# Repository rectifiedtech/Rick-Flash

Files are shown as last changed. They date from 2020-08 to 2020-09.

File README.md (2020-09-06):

# Rick Flash v1.0

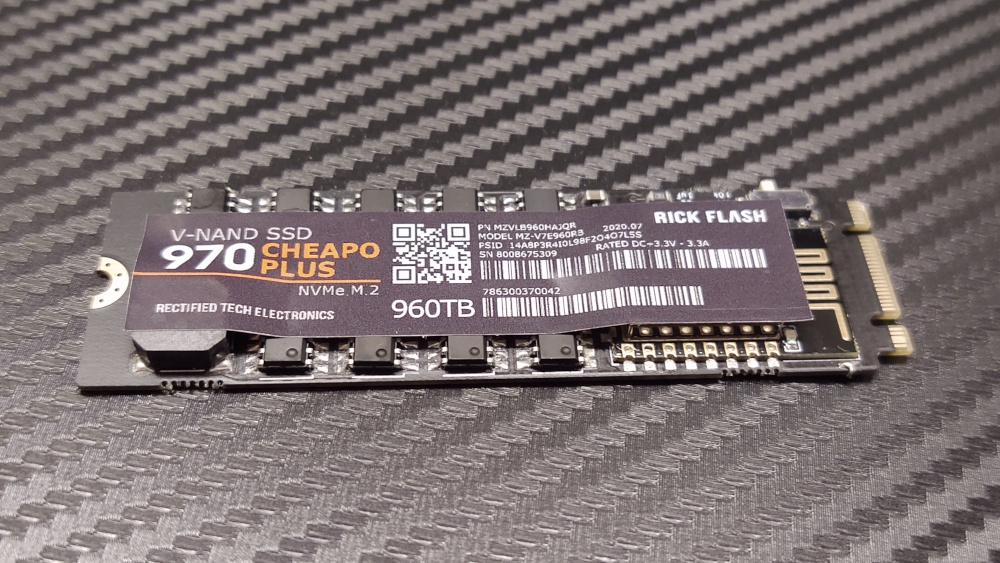
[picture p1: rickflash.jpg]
rickflash

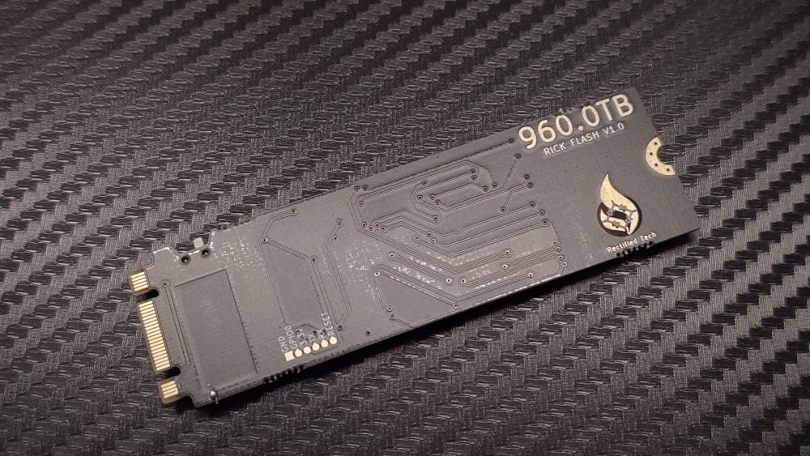
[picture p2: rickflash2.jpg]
rickflash2


### Watch it in action

https://youtu.be/qJRm4iVWZss

(https://www.youtube.com/watch?v=qJRm4iVWZss)

Here's a link to the limited production run of the Rick Flash project - https://www.ebay.com/itm/264855847576 - We might not make anymore of these unless there's more demand.

## Getting Started
1. Insert Rick Flash into an M.2 SSD slot, works with both SATA and NVME SSD slots (B+M Key), keep in mind that the module is a little wider and thicker than a standard M.2 SSD and may not fit in all laptops and desktops perfectly.
2. If the Rick Flash does not make any sound then slide the switch on the side of the M.2 module and try again, you should hear the tune start to play.

## WiFi Connection
### (MAY NOT WORK WITH SOME SAMSUNG PHONES)
When the Rick Flash is powered on it will play a short tune to the Rick Roll song known as “Never Gonna Give You Up” by Rick Astley (you probably already figured this out by now). The Rick Flash creates a WiFi access point called “Free WiFi!”, when connected to it via a phone or computer you will be redirected to a captive portal web page (you may have to tap on “Sign in to Free WiFi!”) on the device that displays “You Got Rick Rolled!!!” with a GIF of Rick Astley along with the lyrics to the song. You can also trigger the song to replay using the web page interface (See Below).

## Remote control over WiFi
1. Power on the Rick Flash and wait until the song stops playing.
2. Connect to the WiFi network called “Free WiFi!” and you should be redirected to a page with a GIF of Rick Astley.
3. Click on the hyperlink called “Click here to trigger the Rick Flash!” and it will replay the song on the Rick Flash remotely. Keep in mind that the WiFi connection may drop out during the song playback and you can only trigger it to replay after the song finishes.

## Programming Pads
The Rick Flash can be reprogrammed using the Arduino IDE and connecting the appropriate pins from a WEMOS D1 Mini Board (without the ESP module soldered) to the programming pads on the back of the M.2 module.

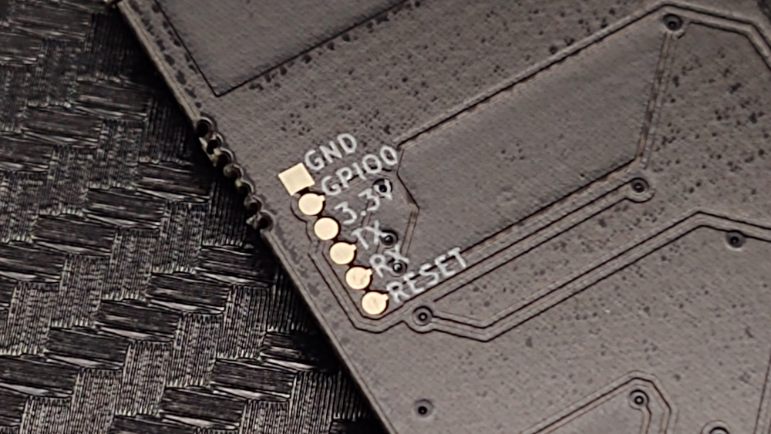
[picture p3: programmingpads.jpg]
programming pads


### Programming the ESP8266
Connect a headless WEMOS D1 Mini board to the Programming pads then upload your code using the arduino IDE with the WEMOS D1 Mini Board selected. Also make sure to write the html and image files to the ESP8266 via SPIFFS by selecting Tools --> ESP8266 Sketch Data Upload. You may need to add the ESP8266 boards to your boards manager as well as the libraries used in the original Arduino code.

## Bill of Materials
| | | | | 
|-----|---|---|---|
| Qty | Description | LCSC #  | Link | 
| 1 | PCB | - | Manufacturer of choice | 
| 1 | ESP-12E | C89297  | https://lcsc.com/product-detail/WIFI-Modules_ESP-12E_C89297.html | 
| 1 | Piezo Buzzer MLT-8530 | C94599  | https://lcsc.com/product-detail/Buzzers_Jiangsu-Huaneng-Elec-MLT-8530_C94599.html | 
| 1 | SMD Slide Swith MSK12C02 | C431540 | https://lcsc.com/product-detail/Toggle-Switches_SHOU-HAN-MSK12C02_C431540.html | 
| 9 | Padauk Microcontroller PMS152-S16 | C317590 | https://lcsc.com/product-detail/PADAUK_PADAUK-Tech-PMS152-S16_C317590.html | 
| 4 | 10k 0805 Resistor | C343942 | https://lcsc.com/product-detail/Chip-Resistor-Surface-Mount_FH-Guangdong-Fenghua-Advanced-Tech-RC-05K103JT_C343942.html | 
| 1 | 1uF 0805 Capacitor | C344171 | https://lcsc.com/product-detail/Others_CCTC-TCC0805X7R105K250DTS_C344171.html |

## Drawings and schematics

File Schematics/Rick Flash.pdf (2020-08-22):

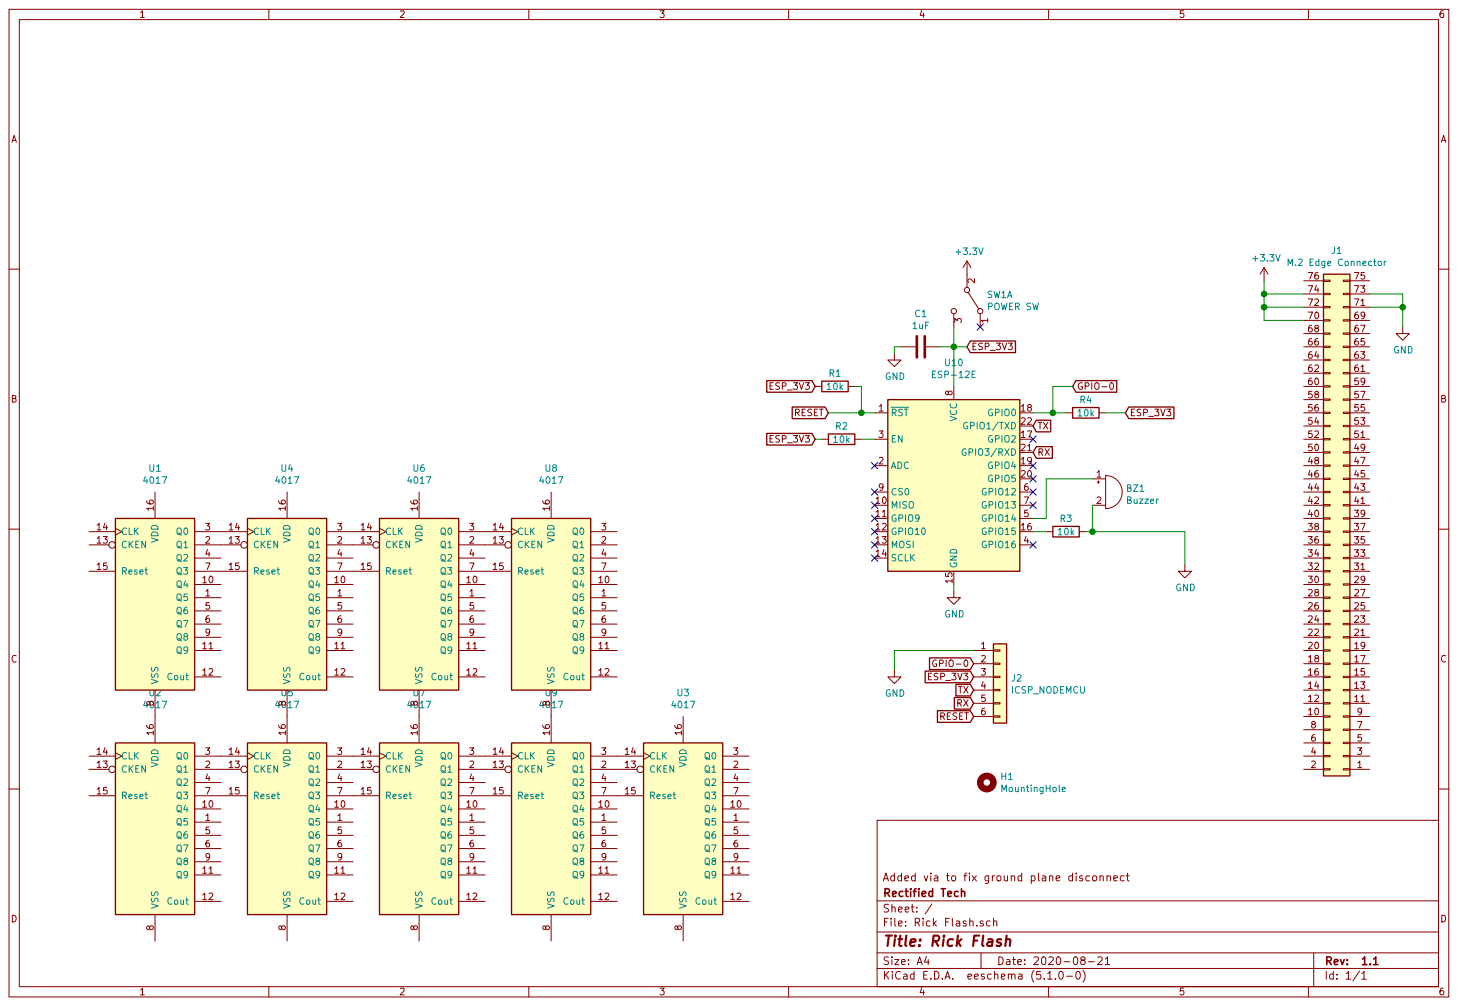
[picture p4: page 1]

Id: 1/1 Title: Rick Flash

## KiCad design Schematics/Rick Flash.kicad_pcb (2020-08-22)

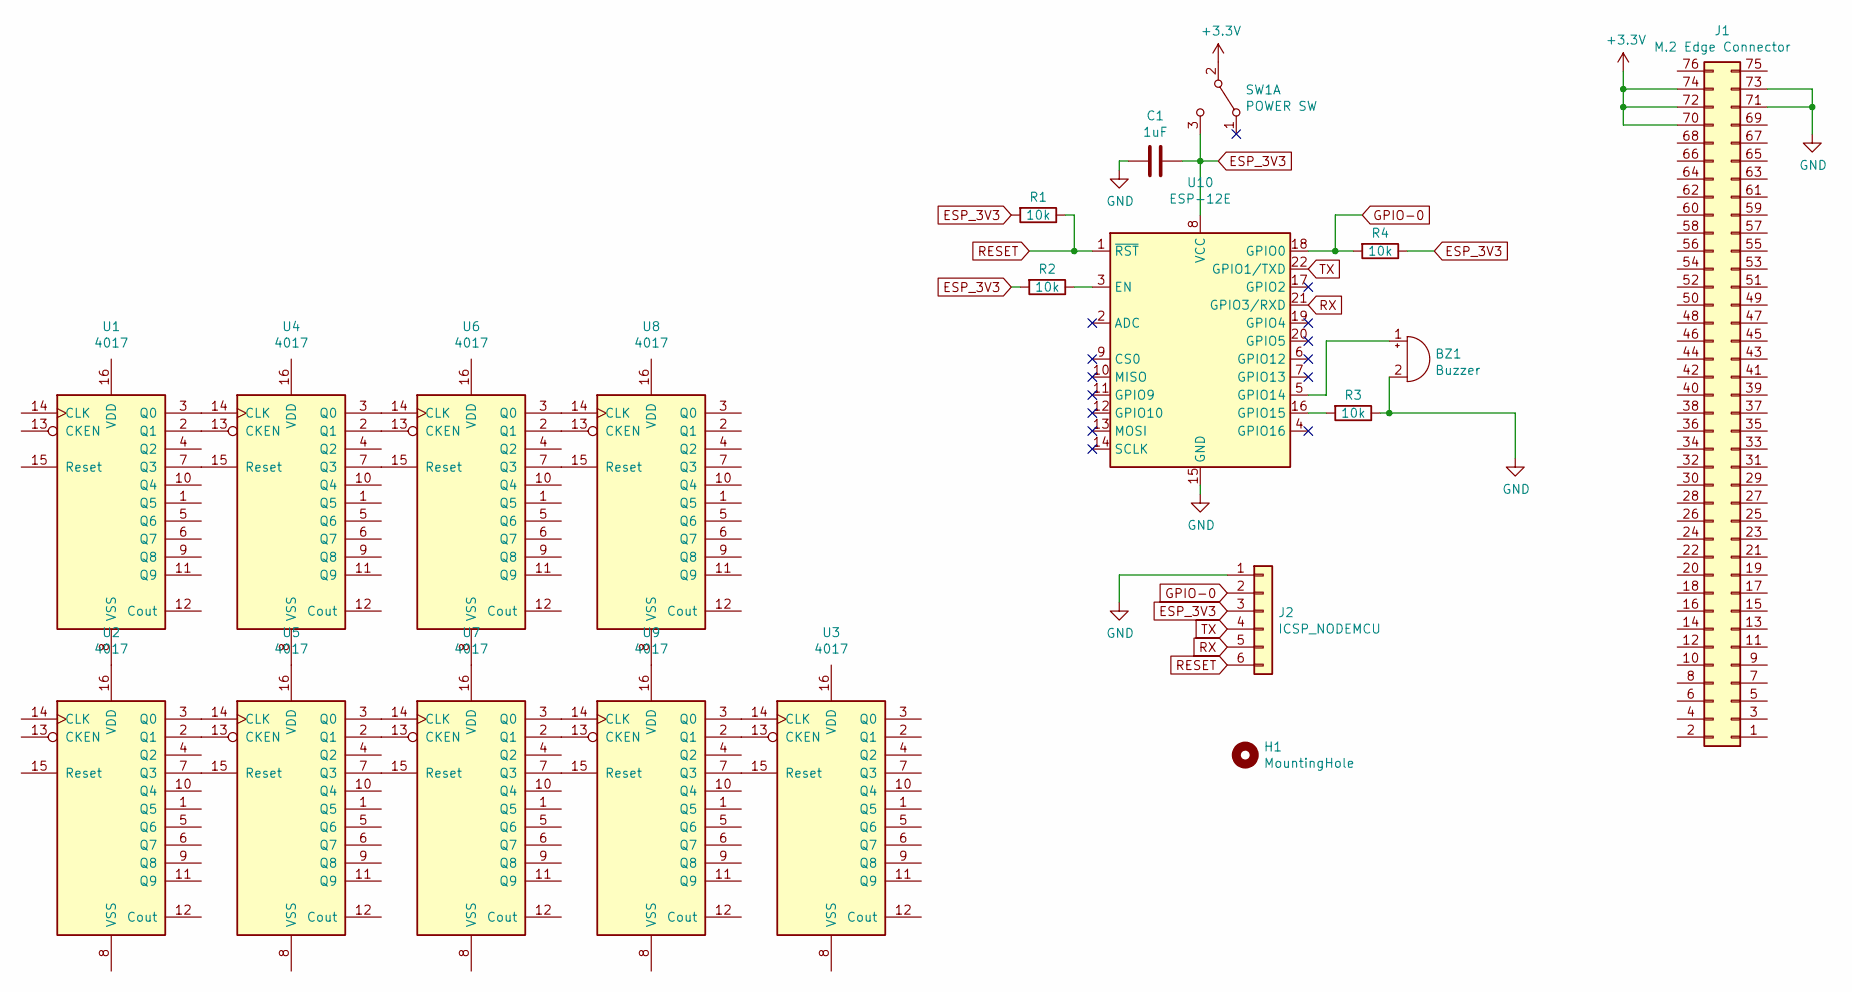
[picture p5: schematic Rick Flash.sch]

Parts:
BZ1: Buzzer; PUIAudio_SMT_0825_S_4_R
C1: 1uF; C_0805_2012Metric
H1: MountingHole; MountingHole_3.2mm_M3_Pad_Via
J1: M.2 Edge Connector; NGFF_B+M
J2: ICSP_NODEMCU; 6pin 1.27mm ICSP Pad
R1, R2, R3, R4: 10k; R_0805_2012Metric
SW1: POWER SW; SW_SPDT_PCM12
U1, U2, U3, U4, U5, U6, U7, U8, U9: 4017; SOP-16_4.4x10.4mm_P1.27mm
U10: ESP-12E

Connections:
+3V3: J1.70, J1.72, J1.74, SW1.2 (B)
ESP_3V3: C1.1, J2.3, R1.2, R2.2, R4.1, SW1.3 (C), U10.8 (VCC)
GND: BZ1.2 (+), C1.2, J1.71, J1.73, J2.1, R3.1, U10.15 (GND)
GPIO-0: J2.2, R4.2, U10.18 (GPIO0)
unnamed: BZ1.1 (-), U10.5 (GPIO14)
unnamed: R2.1, U10.3 (EN)
unnamed: R3.2, U10.16 (GPIO15)
unnamed: U1.2 (Q1), U4.13 (CKEN)
unnamed: U1.3 (Q0), U4.14 (CLK)
unnamed: U1.7 (Q3), U4.15 (Reset)
unnamed: U1.8 (VSS), U2.16 (VDD)
unnamed: U2.2 (Q1), U5.13 (CKEN)
unnamed: U2.3 (Q0), U5.14 (CLK)
unnamed: U2.7 (Q3), U5.15 (Reset)
unnamed: U3.13 (CKEN), U9.2 (Q1)
unnamed: U3.14 (CLK), U9.3 (Q0)
unnamed: U3.15 (Reset), U9.7 (Q3)
unnamed: U4.2 (Q1), U6.13 (CKEN)
unnamed: U4.3 (Q0), U6.14 (CLK)
unnamed: U4.7 (Q3), U6.15 (Reset)
unnamed: U4.8 (VSS), U5.16 (VDD)
unnamed: U5.2 (Q1), U7.13 (CKEN)
unnamed: U5.3 (Q0), U7.14 (CLK)
unnamed: U5.7 (Q3), U7.15 (Reset)
unnamed: U6.2 (Q1), U8.13 (CKEN)
unnamed: U6.3 (Q0), U8.14 (CLK)
unnamed: U6.7 (Q3), U8.15 (Reset)
unnamed: U6.8 (VSS), U7.16 (VDD)
unnamed: U7.2 (Q1), U9.13 (CKEN)
unnamed: U7.3 (Q0), U9.14 (CLK)
unnamed: U7.7 (Q3), U9.15 (Reset)
unnamed: U8.8 (VSS), U9.16 (VDD)
RESET: J2.6, R1.1, U10.1 (~RST)
RX: J2.5, U10.21 (GPIO3/RXD)
TX: J2.4, U10.22 (GPIO1/TXD)

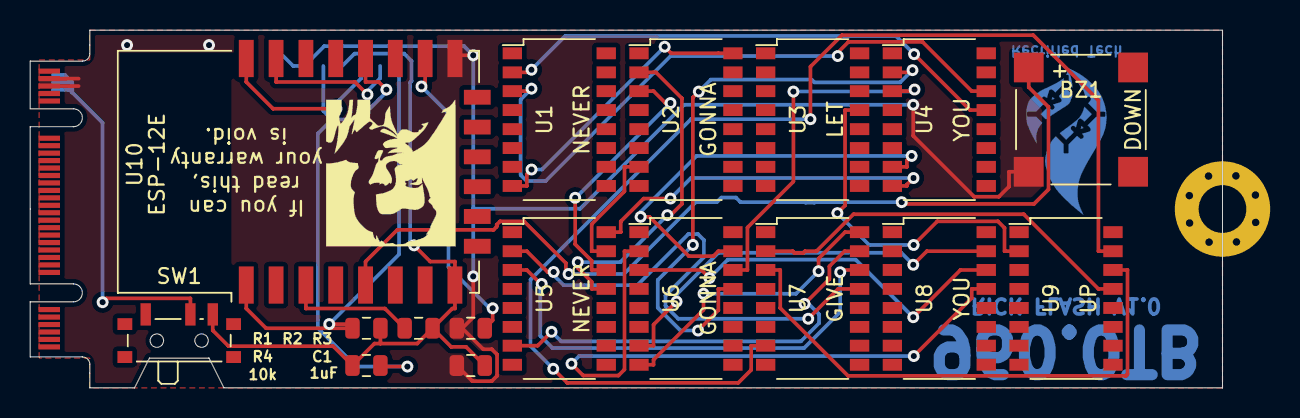
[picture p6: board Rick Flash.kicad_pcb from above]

Board: 2 copper layers, 80.0 x 24.0 mm, 20 parts (1 on the bottom side), 35 nets.

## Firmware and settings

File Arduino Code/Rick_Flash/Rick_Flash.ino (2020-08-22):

//Rick Flash - Designed by Rectified Tech

//Song transposed by robsoncouto


#include <ESP8266WiFi.h>
#include <DNSServer.h>
#include <ESP8266WebServer.h>
#include <ESP8266mDNS.h>
#include <FS.h>

#define NOTE_B0  31
#define NOTE_C1  33
#define NOTE_CS1 35
#define NOTE_D1  37
#define NOTE_DS1 39
#define NOTE_E1  41
#define NOTE_F1  44
#define NOTE_FS1 46
#define NOTE_G1  49
#define NOTE_GS1 52
#define NOTE_A1  55
#define NOTE_AS1 58
#define NOTE_B1  62
#define NOTE_C2  65
#define NOTE_CS2 69
#define NOTE_D2  73
#define NOTE_DS2 78
#define NOTE_E2  82
#define NOTE_F2  87
#define NOTE_FS2 93
#define NOTE_G2  98
#define NOTE_GS2 104
#define NOTE_A2  110
#define NOTE_AS2 117
#define NOTE_B2  123
#define NOTE_C3  131
#define NOTE_CS3 139
#define NOTE_D3  147
#define NOTE_DS3 156
#define NOTE_E3  165
#define NOTE_F3  175
#define NOTE_FS3 185
#define NOTE_G3  196
#define NOTE_GS3 208
#define NOTE_A3  220
#define NOTE_AS3 233
#define NOTE_B3  247
#define NOTE_C4  262
#define NOTE_CS4 277
#define NOTE_D4  294
#define NOTE_DS4 311
#define NOTE_E4  330
#define NOTE_F4  349
#define NOTE_FS4 370
#define NOTE_G4  392
#define NOTE_GS4 415
#define NOTE_A4  440
#define NOTE_AS4 466
#define NOTE_B4  494
#define NOTE_C5  523
#define NOTE_CS5 554
#define NOTE_D5  587
#define NOTE_DS5 622
#define NOTE_E5  659
#define NOTE_F5  698
#define NOTE_FS5 740
#define NOTE_G5  784
#define NOTE_GS5 831
#define NOTE_A5  880
#define NOTE_AS5 932
#define NOTE_B5  988
#define NOTE_C6  1047
#define NOTE_CS6 1109
#define NOTE_D6  1175
#define NOTE_DS6 1245
#define NOTE_E6  1319
#define NOTE_F6  1397
#define NOTE_FS6 1480
#define NOTE_G6  1568
#define NOTE_GS6 1661
#define NOTE_A6  1760
#define NOTE_AS6 1865
#define NOTE_B6  1976
#define NOTE_C7  2093
#define NOTE_CS7 2217
#define NOTE_D7  2349
#define NOTE_DS7 2489
#define NOTE_E7  2637
#define NOTE_F7  2794
#define NOTE_FS7 2960
#define NOTE_G7  3136
#define NOTE_GS7 3322
#define NOTE_A7  3520
#define NOTE_AS7 3729
#define NOTE_B7  3951
#define NOTE_C8  4186
#define NOTE_CS8 4435
#define NOTE_D8  4699
#define NOTE_DS8 4978
#define REST      0


#define DBG_OUTPUT_PORT Serial

const byte DNS_PORT = 53;
const char *ssid = "Free WiFi!";
int clientcount = 0;
int clientcountold = 0;
int minutetimer = 0;

// change this to make the song slower or faster
int tempo = 115;

// change this to whichever pin you want to use
int buzzer = D5;

// notes of the moledy followed by the duration.
// a 4 means a quarter note, 8 an eighteenth , 16 sixteenth, so on
// !!negative numbers are used to represent dotted notes,
// so -4 means a dotted quarter note, that is, a quarter plus an eighteenth!!
int melody[] = {

  // Never Gonna Give You Up - Rick Astley
  // Score available at https://musescore.com/chlorondria_5/never-gonna-give-you-up_alto-sax
  // Arranged by Chlorondria   

  REST,-4, NOTE_A4,8, NOTE_B4,8, NOTE_CS5,8, NOTE_D5,8, NOTE_B4,8, //35
  REST,8, NOTE_E5,8, NOTE_FS5,8, NOTE_E5,-4, NOTE_A4,16, NOTE_B4,16, NOTE_D5,16, NOTE_B4,16,
  NOTE_FS5,-8, NOTE_FS5,-8, NOTE_E5,-4, NOTE_A4,16, NOTE_B4,16, NOTE_D5,16, NOTE_B4,16,
  NOTE_E5,-8, NOTE_E5,-8, NOTE_D5,-8, NOTE_CS5,16, NOTE_B4,8, NOTE_A4,16, NOTE_B4,16, NOTE_D5,16, NOTE_B4,16,
  NOTE_D5,4, NOTE_E5,8, NOTE_CS5,-8, NOTE_B4,16, NOTE_A4,4, NOTE_A4,8, 

  NOTE_E5,4, NOTE_D5,2, NOTE_A4,16, NOTE_B4,16, NOTE_D5,16, NOTE_B4,16, //40
  NOTE_FS5,-8, NOTE_FS5,-8, NOTE_E5,-4, NOTE_A4,16, NOTE_B4,16, NOTE_D5,16, NOTE_B4,16,
  NOTE_A5,4, NOTE_CS5,8, NOTE_D5,-8, NOTE_CS5,16, NOTE_B4,8, NOTE_A4,16, NOTE_B4,16, NOTE_D5,16, NOTE_B4,16,
  NOTE_D5,4, NOTE_E5,8, NOTE_CS5,-8, NOTE_B4,16, NOTE_A4,4, NOTE_A4,8,  
  NOTE_E5,4, NOTE_D5,2, NOTE_A4,16, NOTE_B4,16, NOTE_D5,16, NOTE_B4,16,
   
  NOTE_FS5,-8, NOTE_FS5,-8, NOTE_E5,-4, NOTE_A4,16, NOTE_B4,16, NOTE_D5,16, NOTE_B4,16, //45
  NOTE_A5,4, NOTE_CS5,8, NOTE_D5,-8, NOTE_CS5,16, NOTE_B4,8, NOTE_A4,16, NOTE_B4,16, NOTE_D5,16, NOTE_B4,16,
  NOTE_D5,4, NOTE_E5,8, NOTE_CS5,-8, NOTE_B4,16, NOTE_A4,4, NOTE_A4,8,  
  NOTE_E5,4, NOTE_D5,2, NOTE_A4,16, NOTE_B4,16, NOTE_D5,16, NOTE_B4,16,
  NOTE_FS5,-8, NOTE_FS5,-8, NOTE_E5,-4, NOTE_A4,16, NOTE_B4,16, NOTE_D5,16, NOTE_B4,16, //45
  
  NOTE_A5,4, NOTE_CS5,8, NOTE_D5,-8, NOTE_CS5,16, NOTE_B4,8, NOTE_A4,16, NOTE_B4,16, NOTE_D5,16, NOTE_B4,16,
  NOTE_D5,4, NOTE_E5,8, NOTE_CS5,-8, NOTE_B4,16, NOTE_A4,4, NOTE_A4,8, 

  NOTE_E5,4, NOTE_D5,2, REST,4
};

// sizeof gives the number of bytes, each int value is composed of two bytes (16 bits)
// there are two values per note (pitch and duration), so for each note there are four bytes
int notes = sizeof(melody) / sizeof(melody[0]) / 2;

// this calculates the duration of a whole note in ms
int wholenote = (60000 * 4) / tempo;

int divider = 0, noteDuration = 0;


WiFiEventHandler stationConnectedHandler;
WiFiEventHandler probeRequestPrintHandler;


IPAddress apIP(192, 168, 1, 1);

DNSServer dnsServer;

ESP8266WebServer webServer(80);

void setup() {
 
  Serial.begin(115200);
  Serial.println();

  Serial.print("Configuring access point...");
  
  WiFi.mode(WIFI_AP);
  WiFi.softAPConfig(apIP, apIP, IPAddress(255, 255, 255, 0));
  WiFi.softAP(ssid);

  // if DNSServer is started with "*" for domain name, it will reply with
  // provided IP to all DNS request
  dnsServer.start(DNS_PORT, "*", apIP);

  //start debug port
  DBG_OUTPUT_PORT.begin(115200);
  DBG_OUTPUT_PORT.print("\n");
  DBG_OUTPUT_PORT.setDebugOutput(true);
  SPIFFS.begin();

  //redirect all traffic to index.html
  webServer.onNotFound([]() {
    if(!handleFileRead(webServer.uri())){
      const char *metaRefreshStr = "<head><meta http-equiv=\"refresh\" content=\"0; url=http://192.168.1.1/index.html\" /></head><body><p>redirecting...</p></body>";
      webServer.send(200, "text/html", metaRefreshStr);
    }
  });
  
  webServer.begin();
  
  Serial.print("AP IP address: ");
  Serial.println(apIP);
  Serial.println("HTTP server started");

  stationConnectedHandler = WiFi.onSoftAPModeStationConnected(&onStationConnected);
  probeRequestPrintHandler = WiFi.onSoftAPModeProbeRequestReceived(&onProbeRequestPrint);
Serial.println("Done configuring AP!");
  webServer.on("/trigger", handleTRIGGER); //as Per  <a href="ledOn">, Subroutine to be called

//Play the song (function)
  rickroll(); 

}

//This is used to check to see when a client connects, however it's not used in this code at the moment
void onStationConnected(const WiFiEventSoftAPModeStationConnected& evt) {
  Serial.println("New Client Connected");
  clientcount = (clientcount + 1);
  Serial.println("Total Clients: ");
  Serial.println(clientcount);

}

//HTML action when triggered link is clicked
void handleTRIGGER() { 
 Serial.println("Rick Flash Successfully Triggered");
  rickroll(); //Play the song
//Display that the Rick Flash has been triggered when clicked
 webServer.send(200, "text/html", "Rick Flash Successfully Triggered!"); //Send ADC value only to client ajax request
}

//Can't remember why this is here... It might have something to do with detecting client connections
void onProbeRequestPrint(const WiFiEventSoftAPModeProbeRequestReceived& evt) {
}

//This function plays the song
void rickroll() {
Serial.print("Rick Roll Started...");

for (int thisNote = 0; thisNote < notes * 2; thisNote = thisNote + 2) {

    // calculates the duration of each note
    divider = melody[thisNote + 1];
    if (divider > 0) {
      // regular note, just proceed
      noteDuration = (wholenote) / divider;
    } else if (divider < 0) {
      // dotted notes are represented with negative durations!!
      noteDuration = (wholenote) / abs(divider);
      noteDuration *= 1.5; // increases the duration in half for dotted notes
    }

    // we only play the note for 90% of the duration, leaving 10% as a pause
    tone(buzzer, melody[thisNote], noteDuration * 0.9);

    // Wait for the specief duration before playing the next note.
    delay(noteDuration);

    // stop the waveform generation before the next note.
    noTone(buzzer);
  }
  Serial.print("Rick Roll Ended...");

}

void loop() {



//check to see if a client has connected
  dnsServer.processNextRequest();
  webServer.handleClient();


  //This checks to see if a client connects every 5 seconds
  if (millis() > 5000 && probeRequestPrintHandler) {
    probeRequestPrintHandler = WiFiEventHandler(); 
}

//check to see if a client has connected
if (clientcount > clientcountold){
  
 //put code here to run when a new client connects
}

else {

}
clientcountold = clientcount; //previous client count until value goes up

}


//Web server stuff
String getContentType(String filename){
  if(webServer.hasArg("download")) return "application/octet-stream";
  else if(filename.endsWith(".htm")) return "text/html";
  else if(filename.endsWith(".html")) return "text/html";
  else if(filename.endsWith(".css")) return "text/css";
  else if(filename.endsWith(".js")) return "application/javascript";
  else if(filename.endsWith(".png")) return "image/png";
  else if(filename.endsWith(".gif")) return "image/gif";
  else if(filename.endsWith(".jpg")) return "image/jpeg";
  else if(filename.endsWith(".ico")) return "image/x-icon";
  else if(filename.endsWith(".xml")) return "text/xml";
  else if(filename.endsWith(".pdf")) return "application/x-pdf";
  else if(filename.endsWith(".zip")) return "application/x-zip";
  else if(filename.endsWith(".gz")) return "application/x-gzip";
  return "text/plain";
}

//Given a file path, look for it in the SPIFFS file storage. Returns true if found, returns false if not found.
bool handleFileRead(String path){
  DBG_OUTPUT_PORT.println("handleFileRead: " + path);
  if(path.endsWith("/")) path += "index.html";
  String contentType = getContentType(path);
  String pathWithGz = path + ".gz";
  if(SPIFFS.exists(pathWithGz) || SPIFFS.exists(path)){
    if(SPIFFS.exists(pathWithGz))
      path += ".gz";
    File file = SPIFFS.open(path, "r");
    size_t sent = webServer.streamFile(file, contentType);
    file.close();
    return true;
  }
  return false;
}
